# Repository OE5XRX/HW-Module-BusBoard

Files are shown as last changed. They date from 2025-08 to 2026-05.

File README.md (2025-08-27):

# HW-Module-BusBoard

## License

This project is licensed under [CERN-OHL-S-2.0](https://choosealicense.com/licenses/cern-ohl-s-2.0/).

## Badges

<br>
<br>
<br>
<br>
<br>

## Contact

OE5XRX Amateur Radio Club<br>
🌐 https://oe5xrx.org<br>
✉️ info@oe5xrx.org<br>

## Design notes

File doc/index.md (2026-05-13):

---
title: Bus
nav_order: 2
parent: Hardware
description: Backplane für vier Modul-Slots; verteilt +12V/+5V/GND und beherbergt einen 4-Port USB-2.0-Hub für die CM4-Anbindung.
---

# Bus PCB

<table>
  <tr><th>Top</th><th>Bottom</th></tr>
  <tr>
    <td>top</td>
    <td>bottom</td>
  </tr>
</table>

## Übersicht

Die `Bus`-Platine ist die Backplane der Remote Station. Sie nimmt +12V/+5V/GND vom [PowerBoard](../HW-Module-PowerBoard/), führt die I²C-Verbindung vom [CM4 Carrier](../HW-Module-CM4Carrier/) zum PowerBoard, und stellt vier Modul-Slots zur Verfügung. Auf der Rückseite sitzt ein FE1.1s 4-Port-USB-2.0-Hub: er nimmt einen einzelnen USB-Host-Anschluss vom CM4 entgegen und stellt jedem der vier Slots einen eigenen USB-Downstream-Port zur Verfügung. Jeder USB-Port (CM4-Upstream + 4 Downstream zu den Slots) ist mit einem USBLC6-2SC6 ESD-geschützt.

## Block-Diagramm

```mermaid
flowchart LR
    PB["PowerBoard"] -->|"J301<br/>+12V/+5V/GND<br/>+ I²C"| Hub
    CM4["CM4 Carrier"] <-->|"J201<br/>USB host + I²C"| Hub

    subgraph BB ["BusBoard"]
        direction TB
        Hub["FE1.1s<br/>4-Port USB 2.0 Hub"]
    end

    Hub <-->|"USB1 (J401)"| S1["Device-Slot 1"]
    Hub <-->|"USB2 (J501)"| S2["Device-Slot 2"]
    Hub <-->|"USB3 (J601)"| S3["Device-Slot 3"]
    Hub <-->|"USB4 (J701)"| S4["Device-Slot 4"]
```

I²C ist **nicht** zu den Device-Slots durchgeführt — der Bus existiert physisch nur zwischen CM4-Carrier (`J201`) und PowerBoard (`J301`).

## Steckverbinder

Alle 6 Konnektoren sind **Hirose PCN10-20P-2.54DSA** (20 Pin, 2x10, 2.54 mm Raster, Stiftleiste auf der Backplane). Gegenstück auf den Modulen: PCN10-Buchse passender Variante.

| Bezeichner | Rolle | Pin a2/a3 (I²C) | Pin a5/b5 (USB±) |
| --- | --- | --- | --- |
| `J201` | CM4/RPI Connector  | I²C SCL / SDA | USB-Host vom CM4 |
| `J301` | Power Connector | I²C SCL / SDA | NC |
| `J401` | Device Slot 1 | NC | USB1 (Hub-Port 1) |
| `J501` | Device Slot 2 | NC | USB2 (Hub-Port 2) |
| `J601` | Device Slot 3 | NC | USB3 (Hub-Port 3) |
| `J701` | Device Slot 4 | NC | USB4 (Hub-Port 4) |

USB-Hub-Mapping: USB1→Slot1, USB2→Slot2, USB3→Slot3, USB4→Slot4 (in Reihenfolge der FE1.1s-Ports).

## Pin-Belegung (Power identisch, Signale rollenspezifisch)

Power- und GND-Pins sind auf allen 6 Konnektoren physisch identisch verschaltet. Signal-Pins (I²C, USB) sind je nach Konnektor-Rolle unterschiedlich belegt — siehe vorige Tabelle. Die folgende Pin-Map zeigt die *Position* der Signale; ob diese Pins angeschlossen sind, hängt vom konkreten Konnektor ab.

| Pin | Net | Pin | Net |
|----:|-----|----:|-----|
| a1  | GND | b1  | GND |
| a2  | I²C SCL ¹ | b2  | NC |
| a3  | I²C SDA ¹ | b3  | NC |
| a4  | NC | b4  | NC |
| a5  | USB D+ ² | b5  | USB D- ² |
| a6  | +5V | b6  | +5V |
| a7  | +5V | b7  | +5V |
| a8  | GND | b8  | GND |
| a9  | +12V | b9  | +12V |
| a10 | +12V | b10 | +12V |

¹ **I²C nur auf `J201` (CM4) und `J301` (Power)** — auf den 4 Device-Slots sind die I²C-Pins (a2, a3) **nicht** angeschlossen.
² **USB D+/D-** sind auf `J201` (Upstream vom CM4) und auf `J401`–`J701` (Downstream je Slot) belegt; auf `J301` (Power) sind diese Pins NC.

Verteilung der Versorgung: **4× GND**, **4× +5V**, **4× +12V** über die 20 Pins — bewusst redundant verteilt zur Senkung des Kontaktwiderstands und für höhere Stromtragfähigkeit pro Pin.

## Komponenten

| Bauteil | Funktion |
| --- | --- |
| **FE1.1s** | 4-Port USB-2.0-Hub-Controller. Selbst-powered durch +5V vom Bus. Nimmt USB-Upstream von `J201` (CM4 USB-Host) entgegen, stellt USB1–USB4 zur Verfügung. |
| **USBLC6-2SC6** (5×) | TVS-Diode mit ESD-Schutz für USB-Datenleitungen. Eine Instanz pro USB-Port: 1× auf `J201` (Upstream), 4× auf `J401`–`J701` (Downstream je Slot). |
| **Crystal** | Taktquelle für den FE1.1s. |

Hinweis: Das FE1.1s erzeugt seine internen Rails (VD18 ≈ 1.8 V, VD33 ≈ 3.3 V) selbst aus +5V und führt sie *nicht* an den Bus.

## Bestückung

Keine Hand-Löt-Schritte bekannt — Standard JLCPCB-Bestückung deckt FE1.1s, USBLC6, Crystal und alle Konnektoren ab.

## Bringup

Nach Bestückung und mit PowerBoard + CM4 angesteckt (Slots leer):

1. **Power-Sanity:** an einem freien Device-Slot zwischen `a6` und `a1` messen → +5V; zwischen `a9` und `a1` → +12V (= PowerBoard-Eingang). Auf allen 4 Device-Slots identisch.
2. **USB-Enumeration:** vom CM4 `lsusb` ausführen → ein "FE1.1s Hub" (Vendor 1a40:0101 oder ähnlich) muss sichtbar sein. Wenn ja, USB-Upstream + Hub funktionieren.
3. **I²C-Sanity:** vom CM4 `i2cdetect -y 1` ausführen → die zwei INA226-Adressen des PowerBoards (`0x40`, `0x41`) müssen ACKen.

## Verwandte Module

- [PowerBoard](../HW-Module-PowerBoard/) — speist +5V/+12V auf `J301` ein und sitzt mit den beiden INA226 auf dem I²C.
- [CM4 Carrier](../HW-Module-CM4Carrier/) — liefert USB-Host und I²C-Master auf `J201`.

## Daten

- [Schaltplan]({{ site.data.project.name }}-schematic.pdf)
- [BOM]({{ site.data.project.name }}-bom.html)
- [iBOM]({{ site.data.project.name }}-ibom.html)
- [JLCPCB fabrication & stencil](JLCPCB/{{ site.data.project.name }}-_JLCPCB_compress.zip)
- [JLCPCB Bom](JLCPCB/{{ site.data.project.name }}_bom_jlc.csv)
- [JLCPCB Pick&Place](JLCPCB/{{ site.data.project.name }}_cpl_jlc.csv)

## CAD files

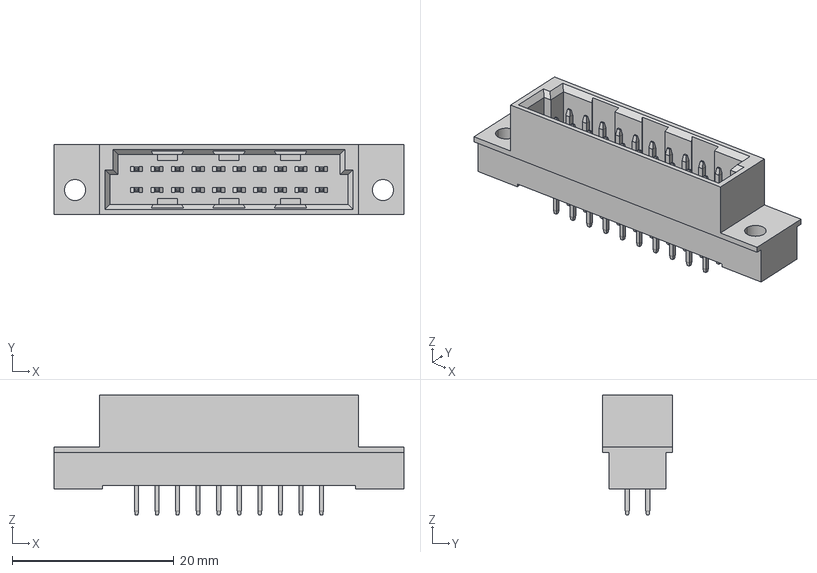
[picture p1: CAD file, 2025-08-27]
3d-models/PCN10-20P-2.54DSA.stp
43.3 x 8.60 x 14.8 mm

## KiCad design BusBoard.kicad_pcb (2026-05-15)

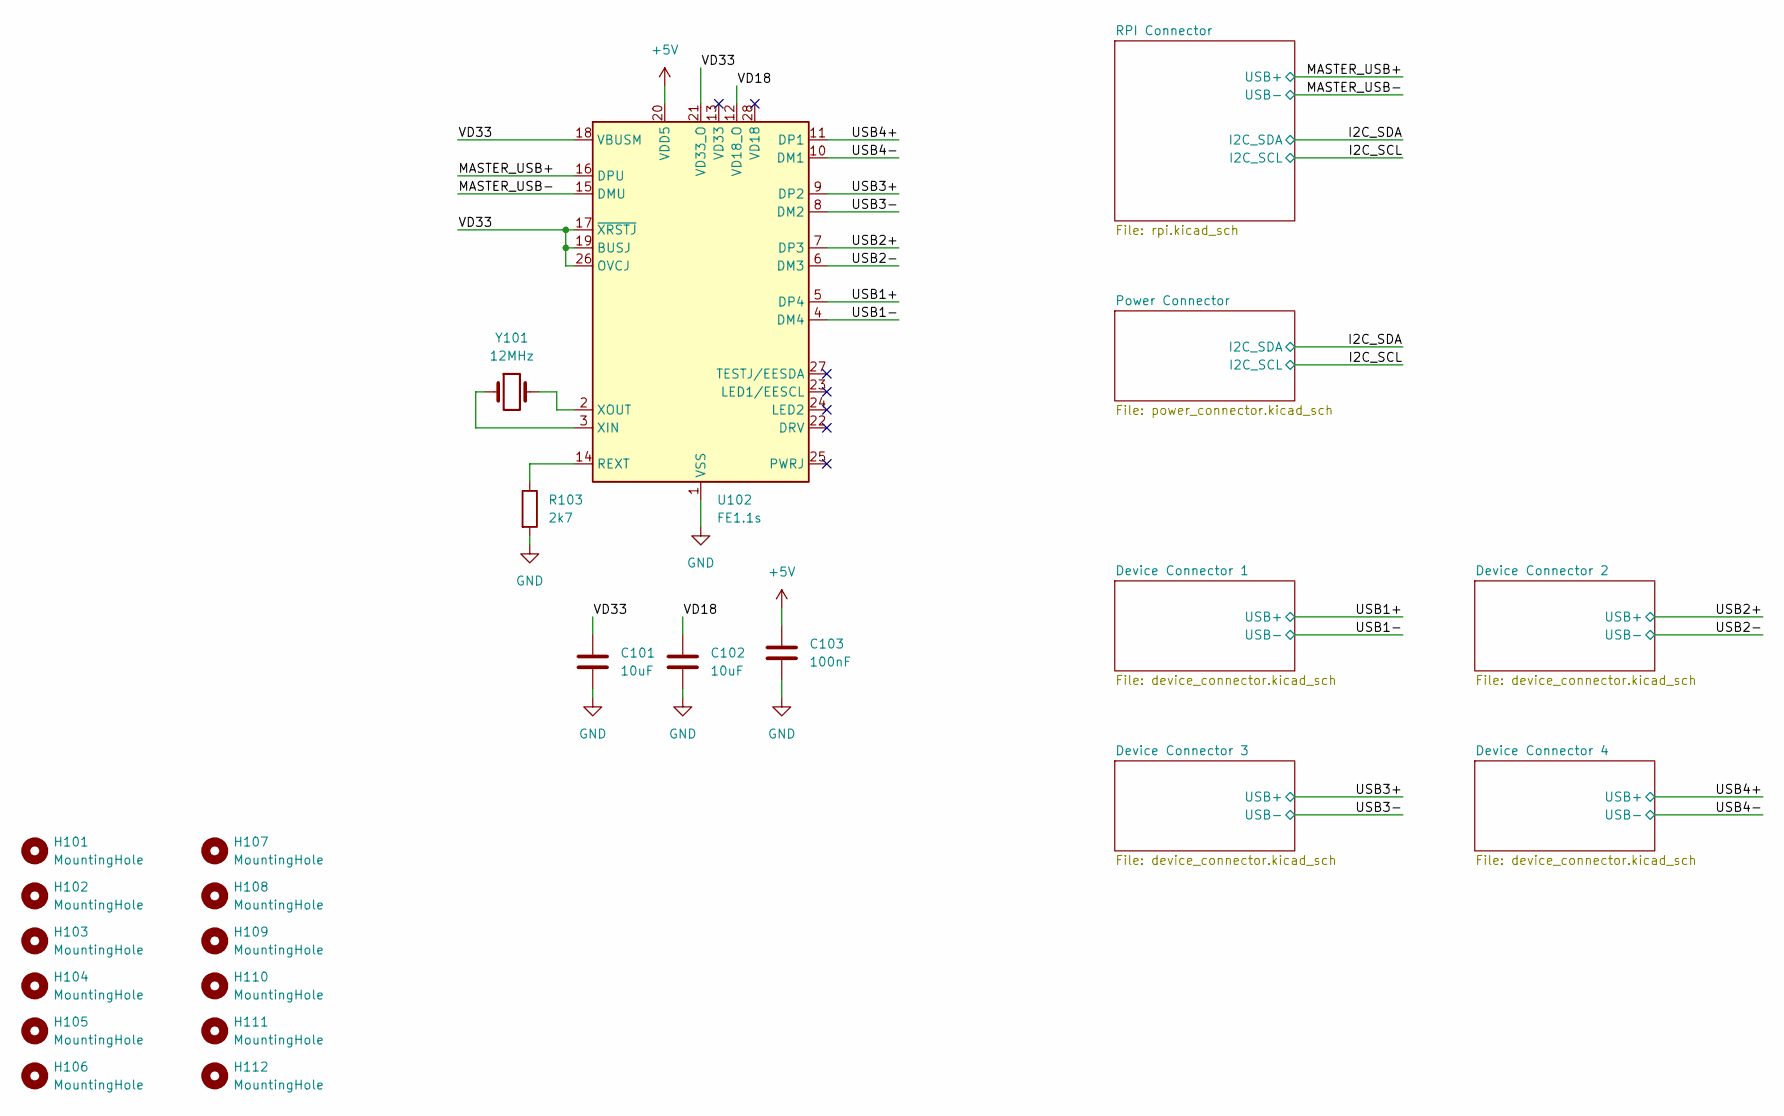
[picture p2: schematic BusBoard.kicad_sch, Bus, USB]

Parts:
C101, C102: 10uF; C_0805_2012Metric; LCSC C13585
C103: 100nF; C_0805_2012Metric; LCSC C28233
H101, H102, H103, H104, H105, H106, H107, H108, H109, H110, H111, H112: MountingHole; MountingHole_3.2mm_M3
R103: 2k7; R_0805_2012Metric; LCSC C352230
U102: FE1.1s; SSOP-28_3.9x9.9mm_P0.635mm; LCSC C6706491
Y101: 12MHz; M49S-SMD; LCSC C2983432

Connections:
+5V: C103.1, U102.20 (VDD5); also elsewhere on the board
/MASTER_USB+: U102.16 (DPU); also elsewhere on the board
/MASTER_USB-: U102.15 (DMU); also elsewhere on the board
/USB1+: U102.5 (DP4); also elsewhere on the board
/USB1-: U102.4 (DM4); also elsewhere on the board
/USB2+: U102.7 (DP3); also elsewhere on the board
/USB2-: U102.6 (DM3); also elsewhere on the board
/USB3+: U102.9 (DP2); also elsewhere on the board
/USB3-: U102.8 (DM2); also elsewhere on the board
/USB4+: U102.11 (DP1); also elsewhere on the board
/USB4-: U102.10 (DM1); also elsewhere on the board
/VD18: C102.1, U102.12 (VD18_O)
/VD33: C101.1, U102.17 (~XRSTJ), U102.18 (VBUSM), U102.19 (BUSJ), U102.21 (VD33_O), U102.26 (OVCJ)
GND: C101.2, C102.2, C103.2, R103.2, U102.1 (VSS); also elsewhere on the board
unnamed: R103.1, U102.14 (REXT)
unnamed: U102.3 (XIN), Y101.1
unnamed: U102.2 (XOUT), Y101.2

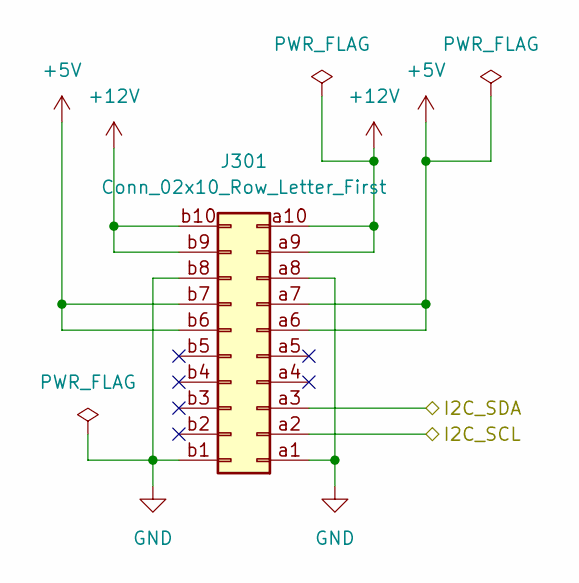
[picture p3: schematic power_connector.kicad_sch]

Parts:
J301: Conn_02x10_Row_Letter_First; PCN10-20P-2.54DSA; MOUSER 798-PCN1020P254DSA72

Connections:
+5V: J301.a6, J301.a7, J301.b6, J301.b7; also elsewhere on the board
+12V: J301.a9, J301.a10, J301.b9, J301.b10; also elsewhere on the board
/I2C_SCL: J301.a2; also elsewhere on the board
/I2C_SDA: J301.a3; also elsewhere on the board
GND: J301.a1, J301.a8, J301.b1, J301.b8; also elsewhere on the board

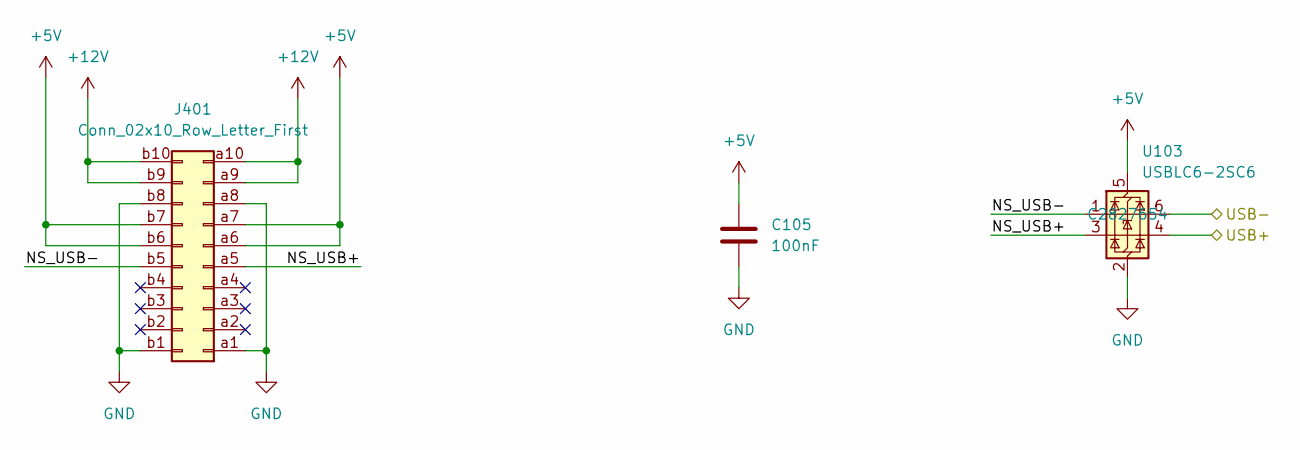
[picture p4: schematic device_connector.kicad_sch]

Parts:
C105: 100nF; C_0805_2012Metric; LCSC C28233
J401: Conn_02x10_Row_Letter_First; PCN10-20P-2.54DSA; MOUSER 798-PCN1020P254DSA72
U103: USBLC6-2SC6; SOT-23-6; LCSC C2827654

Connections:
+5V: C105.1, J401.a6, J401.a7, J401.b6, J401.b7, U103.5 (VBUS); also elsewhere on the board
+12V: J401.a9, J401.a10, J401.b9, J401.b10; also elsewhere on the board
/Device Connector 1/NS_USB+: J401.a5, U103.3 (I/O2)
/Device Connector 1/NS_USB-: J401.b5, U103.1 (I/O1)
/USB1+: U103.4 (I/O2); also elsewhere on the board
/USB1-: U103.6 (I/O1); also elsewhere on the board
GND: C105.2, J401.a1, J401.a8, J401.b1, J401.b8, U103.2 (GND); also elsewhere on the board

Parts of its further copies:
C106, C107, C108: 100nF; C_0805_2012Metric; LCSC C28233
J501, J601, J701: Conn_02x10_Row_Letter_First; PCN10-20P-2.54DSA; MOUSER 798-PCN1020P254DSA72
U104, U105, U106: USBLC6-2SC6; SOT-23-6; LCSC C2827654

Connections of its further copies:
+5V: C106.1, C107.1, C108.1, J501.a6, J501.a7, J501.b6, J501.b7, J601.a6, J601.a7, J601.b6, J601.b7, J701.a6, J701.a7, J701.b6, J701.b7, U104.5 (VBUS), U105.5 (VBUS), U106.5 (VBUS); also elsewhere on the board
+12V: J501.a9, J501.a10, J501.b9, J501.b10, J601.a9, J601.a10, J601.b9, J601.b10, J701.a9, J701.a10, J701.b9, J701.b10; also elsewhere on the board
/Device Connector 2/NS_USB+: J501.a5, U104.3 (I/O2)
/Device Connector 2/NS_USB-: J501.b5, U104.1 (I/O1)
/Device Connector 3/NS_USB+: J601.a5, U105.3 (I/O2)
/Device Connector 3/NS_USB-: J601.b5, U105.1 (I/O1)
/Device Connector 4/NS_USB+: J701.a5, U106.3 (I/O2)
/Device Connector 4/NS_USB-: J701.b5, U106.1 (I/O1)
/USB2+: U104.4 (I/O2); also elsewhere on the board
/USB2-: U104.6 (I/O1); also elsewhere on the board
/USB3+: U105.4 (I/O2); also elsewhere on the board
/USB3-: U105.6 (I/O1); also elsewhere on the board
/USB4+: U106.4 (I/O2); also elsewhere on the board
/USB4-: U106.6 (I/O1); also elsewhere on the board
GND: C106.2, C107.2, C108.2, J501.a1, J501.a8, J501.b1, J501.b8, J601.a1, J601.a8, J601.b1, J601.b8, J701.a1, J701.a8, J701.b1, J701.b8, U104.2 (GND), U105.2 (GND), U106.2 (GND); also elsewhere on the board

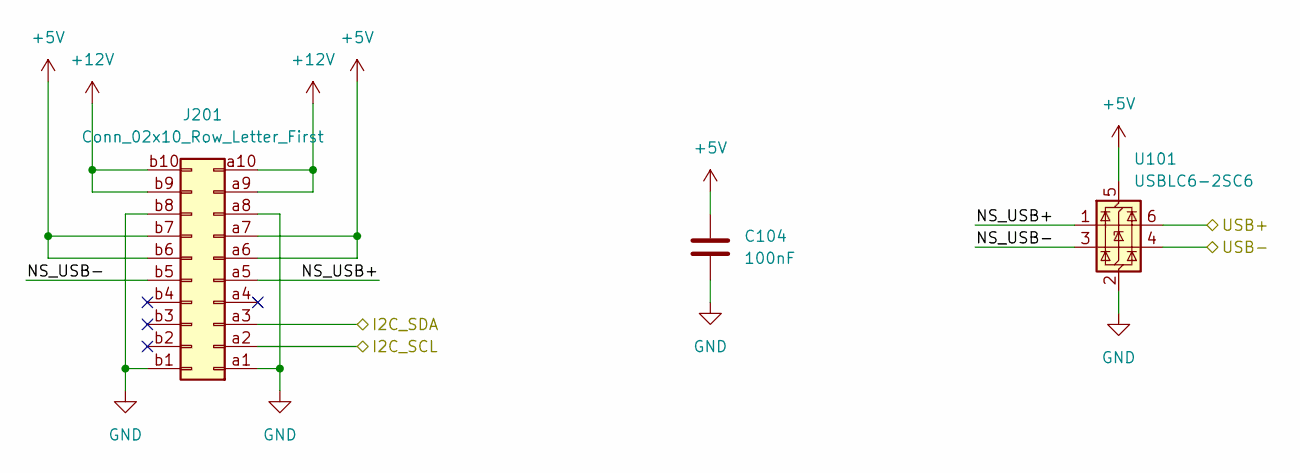
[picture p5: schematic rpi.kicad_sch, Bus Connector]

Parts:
C104: 100nF; C_0805_2012Metric; LCSC C28233
J201: Conn_02x10_Row_Letter_First; PCN10-20P-2.54DSA; MOUSER 798-PCN1020P254DSA72
U101: USBLC6-2SC6; SOT-23-6; LCSC C2827654

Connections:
+5V: C104.1, J201.a6, J201.a7, J201.b6, J201.b7, U101.5 (VBUS); also elsewhere on the board
+12V: J201.a9, J201.a10, J201.b9, J201.b10; also elsewhere on the board
/I2C_SCL: J201.a2; also elsewhere on the board
/I2C_SDA: J201.a3; also elsewhere on the board
/MASTER_USB+: U101.6 (I/O1); also elsewhere on the board
/MASTER_USB-: U101.4 (I/O2); also elsewhere on the board
/RPI Connector/NS_USB+: J201.a5, U101.1 (I/O1)
/RPI Connector/NS_USB-: J201.b5, U101.3 (I/O2)
GND: C104.2, J201.a1, J201.a8, J201.b1, J201.b8, U101.2 (GND); also elsewhere on the board

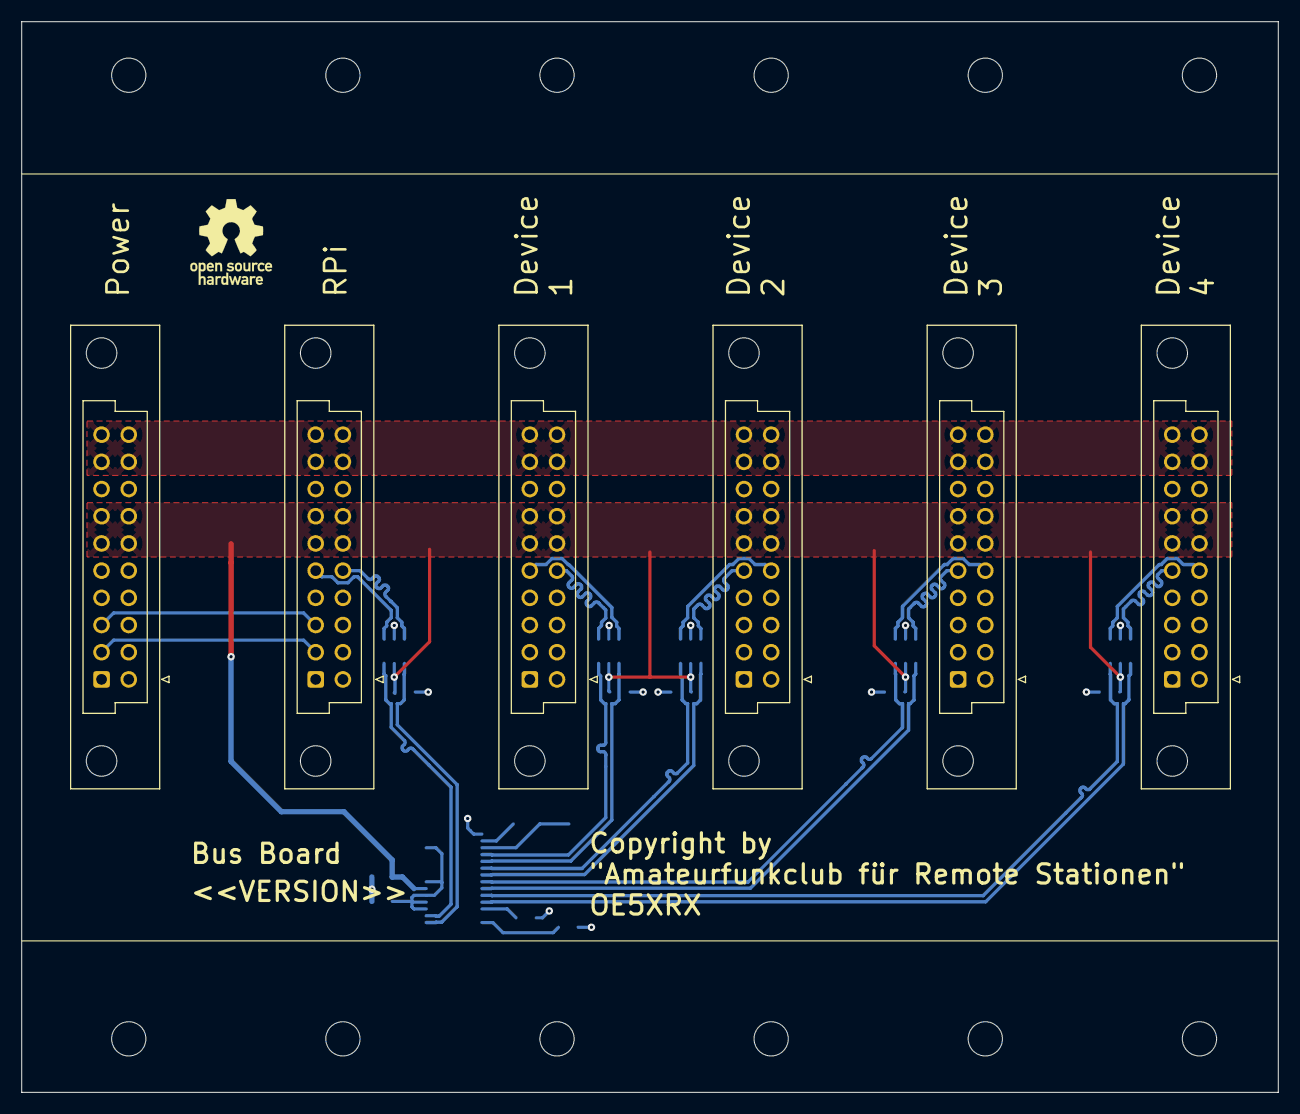
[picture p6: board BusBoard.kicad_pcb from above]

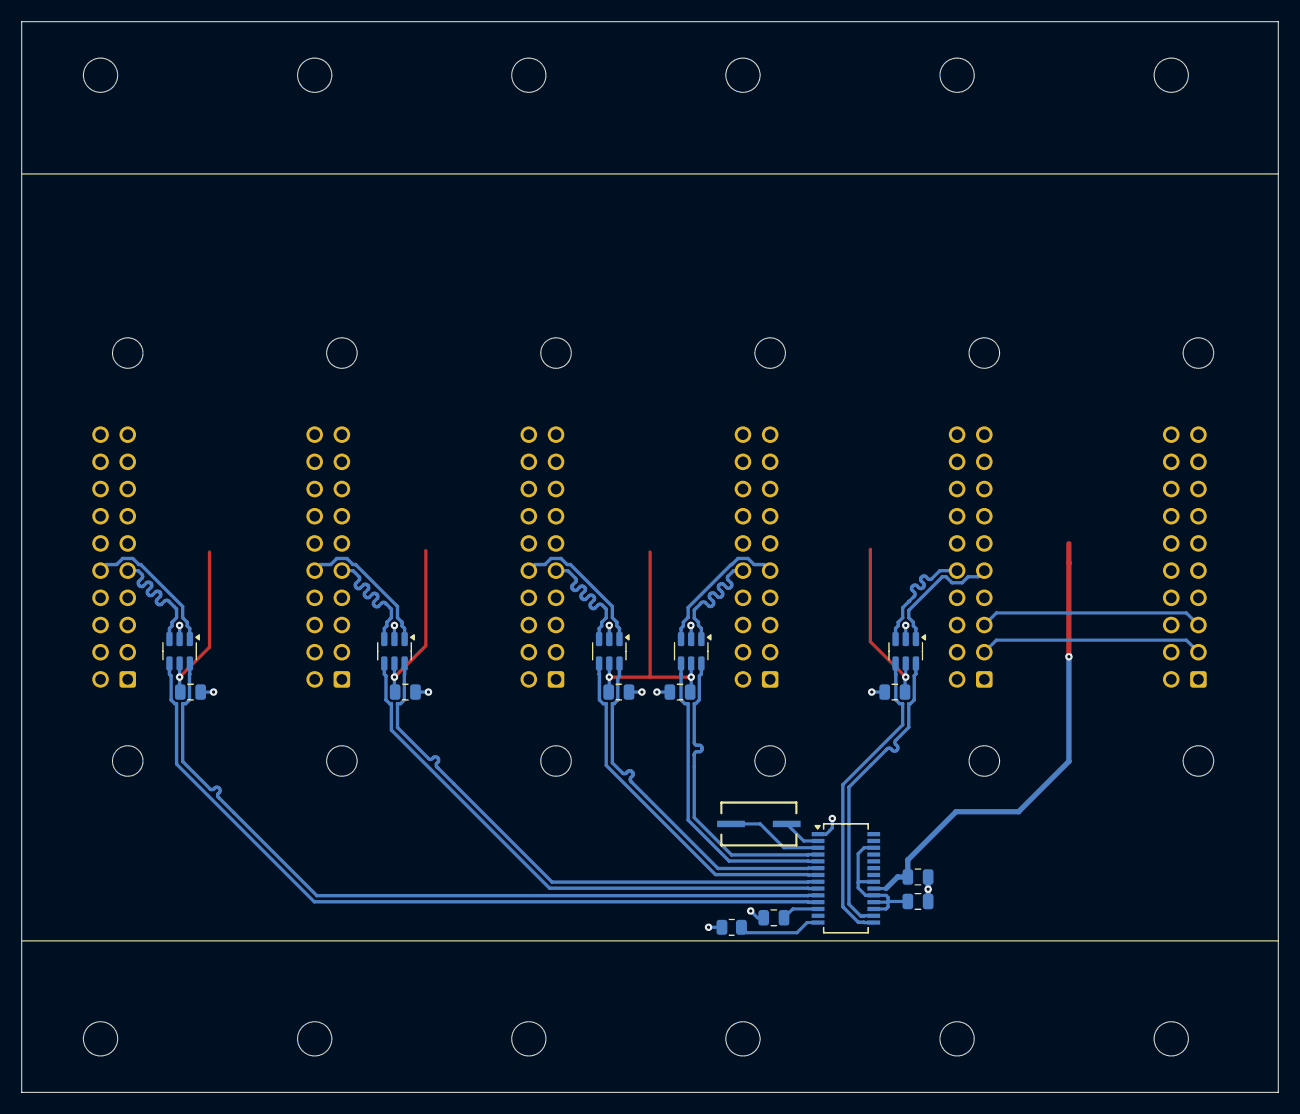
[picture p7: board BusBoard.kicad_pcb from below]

Board: 4 copper layers, 117.4 x 100.0 mm, 34 parts (16 on the bottom side), 30 nets.

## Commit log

2025-08-27 setup new project
    [PCN10-20P-2.54DSA.stp, device_connector.kicad_sch, main.kicad_pcb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]
2025-08-27 fix path
    [main.kicad_pcb]
2025-09-05 🔄 synced local '.github/workflows/create-debug-docs.yaml' with remote '.github/workflows/create-debug-docs.yaml'
2025-09-05 🔄 created local 'doc/_config.yml' from remote 'doc/_config.yml'
2025-09-05 🔄 created local 'doc/favicon.ico' from remote 'doc/favicon.ico'
2025-09-05 🔄 created local 'Gemfile' from remote 'Gemfile'
2026-05-12 rename(kicad): main.kicad_* → BusBoard.kicad_*
    Distinguishable KiCad window titles on the desktop. The composite action
    in HW-Module-CI auto-detects the project name from the basename of
    *.kicad_pro, so CI behaviour is identical before and after — only the
    artefact filenames change (main-bom.html → BusBoard-bom.html etc.),
    which doc/index.md already routes through {{ site.data.project.name }}.
    Internal references updated:
    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
    [BusBoard.kicad_pcb, BusBoard.kicad_sch]
2026-05-12 docs: rewrite Bus index.md with overview, block-diagram, full 20-pin pinout
    Adds:
    - 1-sentence description front-matter
    - Übersicht highlighting the role as backplane (power distribution +
    4-port USB hub for CM4 → slots)
    - Mermaid block diagram showing the topology (PowerBoard, CM4, 4 slots
    meeting on the BusBoard with FE1.1s in the middle)
    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
2026-05-13 fix(docs): adressiere 4 Copilot-Review-Findings auf PR #5
    1. Mermaid: 'BB' wurde sowohl als Subgraph-ID als auch als Node-Ziel
    verwendet (PB → BB / CM4 → BB UND subgraph BB [...]). Umbenannt:
    die Hub-Node heisst jetzt 'Hub', der BusBoard-Subgraph bleibt 'BB'.
    2. Pin-Belegung-Überschrift war widersprüchlich: 'identisch auf allen
    Konnektoren' obwohl Signale sich je Rolle unterscheiden. Neu:
    'Power identisch, Signale rollenspezifisch'.
    3. Unicode-Minus (U+2212) in 'USB D−' durch ASCII '-' ersetzt. Hilft
    Copy/Paste und Volltextsuche.
    4. Gemischte Anführungszeichen bei lsusb-Beispiel: '„FE1.1s Hub"'
    hatte deutsches öffnendes Quote + englisches schließendes. Auf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
2026-05-15 chore: migrate <<HASH>> placeholder to <<VERSION>> (#7)
    Aligns the KiCad title-block placeholder with the new versioning concept
    documented at oe5xrx.org/docs/remote-station/hardware/versioning/.
    The placeholder is substituted at CI time:
    - Release build: v1.5 → "1.5" (semver only, no `v`, no SHA)
    - Debug build: "BETA-<short-commit>"
    No electrical or layout change — pure text replacement on the title-block
    silkscreen text. Requires HW-Module-CI feat/version-placeholder
    (OE5XRX/HW-Module-CI#4) to be merged first; otherwise CI substitutes
    the old <<HASH>> token and leaves the new <<VERSION>> string literal
    in the title block until the CI side catches up.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
    [BusBoard.kicad_pcb, BusBoard.kicad_sch, device_connector.kicad_sch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]

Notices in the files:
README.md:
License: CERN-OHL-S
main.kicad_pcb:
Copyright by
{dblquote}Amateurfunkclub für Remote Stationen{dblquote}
